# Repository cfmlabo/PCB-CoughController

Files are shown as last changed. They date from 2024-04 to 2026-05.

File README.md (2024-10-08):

# カフコントローラ用基板

- カフスイッチ(Switch + LED)最大５+２個  
  - J9は予備(SW6, SW7)なので実装しなくてよい
- オーディオリレー  
  - APSでは使用しないので実装しなくてよい
- GPIO(IN 8/OUT 8)  

[BOM](./BOM.md)

## CPI-DIO対応表

### Board1 / IN

| ピン番号 | 機能 |
| -- | -- |
| 1 | NC |
| 2 | SW 7 |
| 3 | SW 6 |
| 4 | SW 5 |
| 5 | SW 4 |
| 6 | SW 3 |
| 7 | SW 2 |
| 8 | SW 1 |

### Board1 / OUT

| ピン番号 | 機能 |
| -- | -- |
| 1 | リレー |
| 2 | SW 7 |
| 3 | SW 6 |
| 4 | SW 5 |
| 5 | SW 4 |
| 6 | SW 3 |
| 7 | SW 2 |
| 8 | SW 1 |

### Board2 / IN

| ピン番号 | 機能 |
| -- | -- |
| 1 | IN 8 |
| 2 | IN 7 |
| 3 | IN 6 |
| 4 | IN 5 |
| 5 | IN 4 |
| 6 | IN 3 |
| 7 | IN 2 |
| 8 | IN 1 |

### Board2 / OUT

| ピン番号 | 機能 |
| -- | -- |
| 1 | OUT 8 |
| 2 | OUT 7 |
| 3 | OUT 6 |
| 4 | OUT 5 |
| 5 | OUT 4 |
| 6 | OUT 3 |
| 7 | OUT 2 |
| 8 | OUT 1 |

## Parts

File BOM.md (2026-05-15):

# 部品一覧表

| No. | Ref | 数量 | 部品名 | 名称 | |
| -- | -- | -- | -- | -- | -- |
| 1 | C1 | 1 | 0.1uF | セラミックコンデンサ | [秋月](https://akizukidenshi.com/catalog/g/g100090/) |
| 2 | C2 | 1 | 100uF/25V | 電解コンデンサ | [秋月](https://akizukidenshi.com/catalog/g/g117877/) |
| 3 | D1, D2 | 2 | 1S1588 | 整流ダイオード | [秋月(代替品)](https://akizukidenshi.com/catalog/g/g116835/) |
| 4 | J1, J2, J3, J4, J5, J6 | 6 | 2x10 | ピンヘッダ(ボックス) | [秋月](https://akizukidenshi.com/catalog/g/g113180/)|
| 5 | K1, K2 | 2 | G6A-274P DC5V | リレー | [モノタロウ](https://www.monotaro.com/p/4080/2257/)|
| 6 | R1, R2, R6, R7 | 4 | 10K | 抵抗 | 社内在庫品 |
| 7 | R3, R4, R5, R8 | 4 | 220 | 抵抗 | 社内在庫品 |
| 8 | R9, R10, R11, R12, R13, R14, R15, R16, R17, R18, R19, R20, R21, R22, R23, R24 | 16 | 510 | 抵抗 | 社内在庫品 |
| 9 | U1, U2, U3, U4, U5, U6, U7, U8 | 8 | TLP224-2 | フォトリレー | 社内在庫品 |

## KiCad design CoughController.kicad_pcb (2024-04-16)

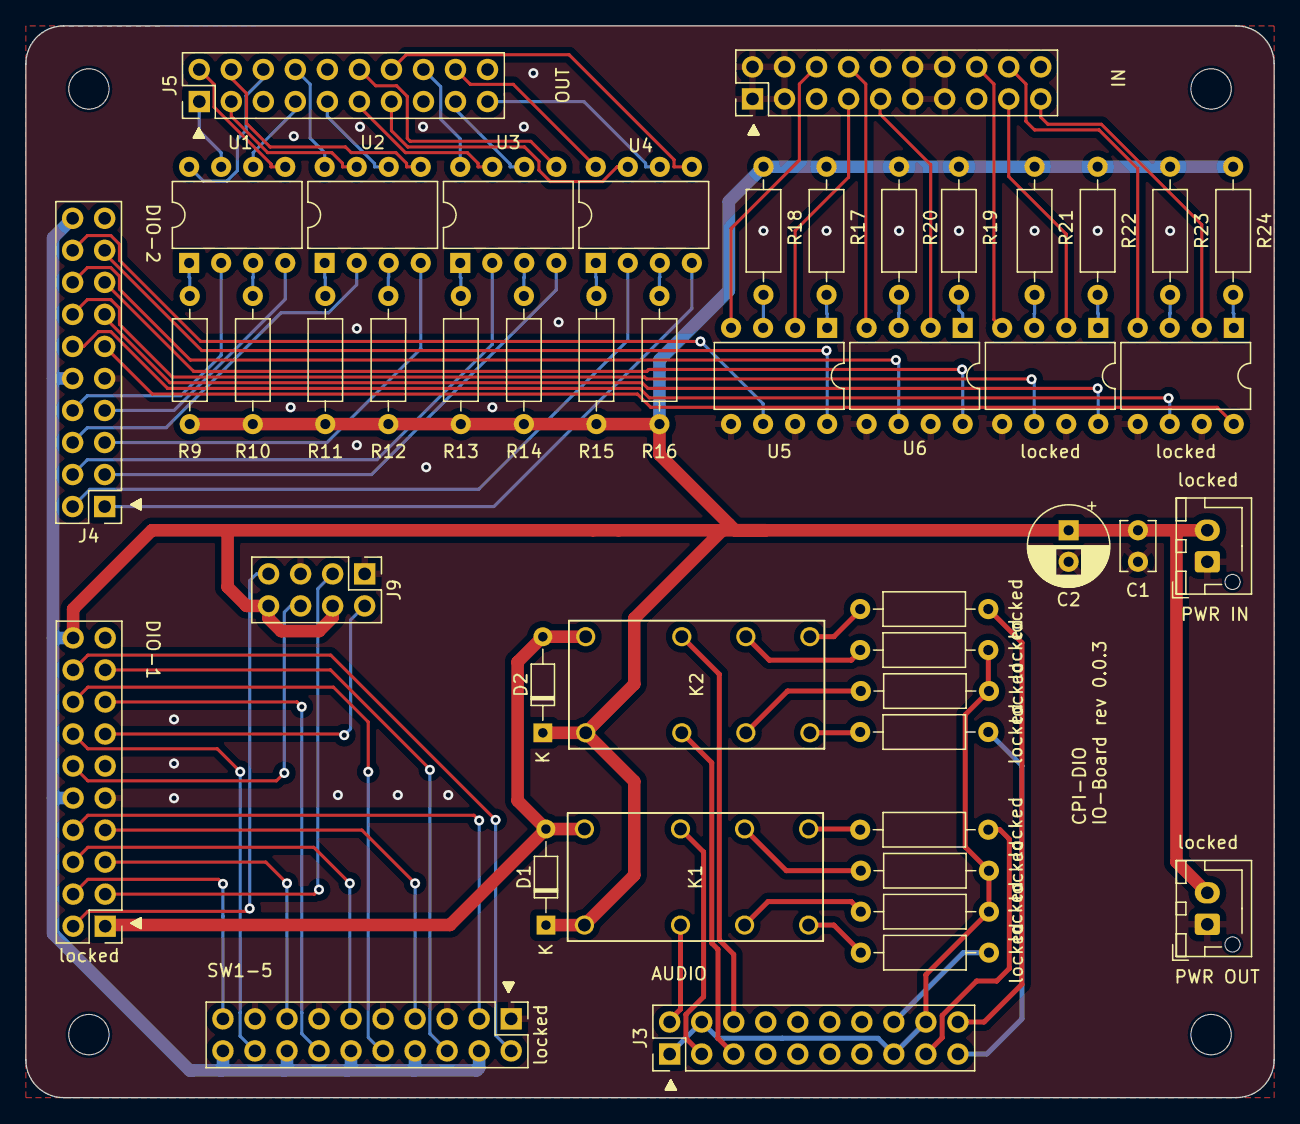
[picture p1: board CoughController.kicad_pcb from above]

Board: 2 copper layers, 99.0 x 85.0 mm, 51 parts (0 on the bottom side), 90 nets.

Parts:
C1: 0.1uF; C_Disc_D3.8mm_W2.6mm_P2.50mm
C2: 100uF/25V; CP_Radial_D6.3mm_P2.50mm
D1, D2: 1S1588; D_DO-34_SOD68_P7.62mm_Horizontal
H1, H2, H3, H4: MountingHole; MountingHole_3.2mm_M3
J3: AUDIO IN/OUT; BoxHeader_2x10_P2.54mm_Vertical
J4: DIO-2; BoxHeader_2x10_P2.54mm_Vertical
J5: GPIO-OUT; BoxHeader_2x10_P2.54mm_Vertical
J6: GPIO-IN; BoxHeader_2x10_P2.54mm_Vertical
J9: Conn_02x04_Odd_Even; PinHeader_2x04_P2.54mm_Vertical
K1, K2: G6A-274P-DC5; RELAY_G6A-274P-DC5
R9, R10, R11, R12, R13, R14, R15, R16, R17, R18, R19, R20, R21, R22, R23, R24: 510; R_Axial_DIN0207_L6.3mm_D2.5mm_P10.16mm_Horizontal
U1, U2, U3, U4, U5, U6: TLP627-2; DIP-8_W7.62mm
locked: SW1-5; BoxHeader_2x10_P2.54mm_Vertical
locked#2, locked#7: TLP627-2; DIP-8_W7.62mm
locked#3, locked#4, locked#9, locked#10: 10K; R_Axial_DIN0207_L6.3mm_D2.5mm_P10.16mm_Horizontal
locked#5, locked#12, locked#13, locked#14: 220; R_Axial_DIN0207_L6.3mm_D2.5mm_P10.16mm_Horizontal
locked#6: DIO-1; BoxHeader_2x10_P2.54mm_Vertical
locked#8: PWR_IN; JST_XH_B2B-XH-AM_1x02_P2.50mm_Vertical
locked#11: PWR_OUT; JST_XH_B2B-XH-AM_1x02_P2.50mm_Vertical

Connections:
AUDIO-IN-L-COLD: J3.3, K1.13
AUDIO-IN-L-GND: J3.1, J3.4, J3.15, J3.18, locked#3.2, locked#4.2, locked#9.1, locked#10.1
AUDIO-IN-L-HOT: J3.2, K1.4
AUDIO-IN-R-COLD: J3.6, K2.13
AUDIO-IN-R-HOT: J3.5, K2.4
AUDIO-OUT-L-COLD: J3.17, locked#14.1
AUDIO-OUT-L-HOT: J3.16, locked#13.2
AUDIO-OUT-R-COLD: J3.20, locked#5.2
AUDIO-OUT-R-HOT: J3.19, locked#12.1
COM0: C1.1, C2.1, D1.1 (K), D2.1 (K), J4.10, J4.20, J9.4, J9.8, K1.1, K2.1, R9.2, R10.2, R11.2, R12.2, R13.2, R14.2, R15.2, R16.2, R17.2, R18.2, R19.2, R20.2, R21.2, R22.2, R23.2, R24.2, locked.4, locked.8, locked.12, locked.16, locked.20, locked#6.10, locked#6.20, locked#8.2, locked#11.2
DIO-2/IN1: J4.18, U5.6
DIO-2/IN2: J4.17, U5.8
DIO-2/IN3: J4.16, U6.6
DIO-2/IN4: J4.15, U6.8
DIO-2/IN5: J4.14, locked#7.6
DIO-2/IN6: J4.13, locked#7.8
DIO-2/IN7: J4.12, locked#2.6
DIO-2/IN8: J4.11, locked#2.8
DIO-2/OUT1: J4.8, U1.2
DIO-2/OUT2: J4.7, U1.4
DIO-2/OUT3: J4.6, U2.2
DIO-2/OUT4: J4.5, U2.4
DIO-2/OUT5: J4.4, U3.2
DIO-2/OUT6: J4.3, U3.4
DIO-2/OUT7: J4.2, U4.2
DIO-2/OUT8: J4.1, U4.4
GND: C1.2, C2.2, J4.9, J6.1, J6.2, J6.3, J6.4, J6.11, J6.12, J6.13, J6.14, J9.1, J9.5, U5.5, U5.7, U6.5, U6.7, locked.1, locked.5, locked.9, locked.13, locked.17, locked#2.5, locked#2.7, locked#6.9, locked#7.5, locked#7.7, locked#8.1, locked#11.1
GPIO-IN/1P: J6.6, U5.4
GPIO-IN/2P: J6.7, U5.2
GPIO-IN/3P: J6.8, U6.4
GPIO-IN/4P: J6.9, U6.2
GPIO-IN/5P: J6.16, locked#7.4
GPIO-IN/6P: J6.17, locked#7.2
GPIO-IN/7P: J6.18, locked#2.4
GPIO-IN/8P: J6.19, locked#2.2
GPIO-OUT/1M: J5.1, U1.7
GPIO-OUT/1P: J5.6, U1.8
GPIO-OUT/2M: J5.2, U1.5
GPIO-OUT/2P: J5.7, U1.6
GPIO-OUT/3M: J5.3, U2.7
GPIO-OUT/3P: J5.8, U2.8
GPIO-OUT/4M: J5.4, U2.5
GPIO-OUT/4P: J5.9, U2.6
GPIO-OUT/5M: J5.11, U3.7
GPIO-OUT/5P: J5.16, U3.8
GPIO-OUT/6M: J5.12, U3.5
GPIO-OUT/6P: J5.17, U3.6
GPIO-OUT/7M: J5.13, U4.7
GPIO-OUT/7P: J5.18, U4.8
GPIO-OUT/8M: J5.14, U4.5
GPIO-OUT/8P: J5.19, U4.6
unnamed: K1.6, locked#9.2
unnamed: K1.8, locked#13.1
unnamed: K1.9, locked#14.2
unnamed: K1.11, locked#3.1
unnamed: K2.6, locked#10.2
unnamed: K2.8, locked#12.2
unnamed: K2.9, locked#5.1
unnamed: K2.11, locked#4.1
unnamed: R9.1, U1.1
unnamed: R10.1, U1.3
unnamed: R11.1, U2.1
unnamed: R12.1, U2.3
unnamed: R13.1, U3.1
unnamed: R14.1, U3.3
unnamed: R15.1, U4.1
unnamed: R16.1, U4.3
unnamed: R17.1, U5.1
unnamed: R18.1, U5.3
unnamed: R19.1, U6.1
unnamed: R20.1, U6.3
unnamed: R21.1, locked#7.3
unnamed: R22.1, locked#7.1
unnamed: R23.1, locked#2.3
unnamed: R24.1, locked#2.1
RY_POW: D1.2 (A), D2.2 (A), K1.16, K2.16, locked#6.1
SW1/L1: locked.3, locked#6.8
SW1/O: locked.2, locked#6.18
SW2/L1: locked.7, locked#6.7
SW2/O: locked.6, locked#6.17
SW3/L1: locked.11, locked#6.6
SW3/O: locked.10, locked#6.16
SW4/L1: locked.15, locked#6.5
SW4/O: locked.14, locked#6.15
SW5/L1: locked.19, locked#6.4
SW5/O: locked.18, locked#6.14
SW6/L1: J9.3, locked#6.3
SW6/O: J9.2, locked#6.13
SW7/L1: J9.7, locked#6.2
SW7/O: J9.6, locked#6.12

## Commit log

2024-03-14 カフコントローラ
    [CoughController.kicad_pcb, CoughController.kicad_sch, DIO1.kicad_sch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]
2024-03-14 コネクタをピンヘッダに変更
    [CoughController.kicad_pcb, DIO1.kicad_sch, DIO2.kicad_sch]
2024-03-14 基板サイズ調整
    [CoughController.kicad_pcb]
2024-03-14 ルーティング見直し
    [CoughController.kicad_pcb]
2024-03-15 端子をピンヘッダ2x10に変更
    [CoughController.kicad_pcb, CoughController.kicad_sch, DIO1.kicad_sch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]
2024-03-29 電源コネクタ フットプリント間違いを修正
    [CoughController.kicad_pcb, CoughController.kicad_sch]
2024-03-29 リレーのフットプリントが間違っていたのを修正
    ピン配置が間違っていた
    [CoughController.kicad_pcb]
2024-03-29 GPIO OUT ジックミスを修正
    電流シンクに変更
    [CoughController.kicad_pcb, DIO2.kicad_sch]
2024-03-29 オーディオ線強化
    [CoughController.kicad_pcb]
2024-04-03 リレー ロジックミス修正
    [CoughController.kicad_pcb, DIO1.kicad_sch]
2024-04-04 AUDIO ソケット位置調整
    ソケットピンヘッダが干渉するので移動
    [CoughController.kicad_pcb]
2024-04-08 SW6/SW7を追加
    [CoughController.kicad_pcb, CoughController.kicad_sch, DIO1.kicad_sch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]
2024-04-08 リファクタリング
    [CoughController.kicad_pcb]
2024-04-08 bugfix GPIO/IN ドライ接点へ修正
    GPIO/INはドライ接点
    [CoughController.kicad_pcb, CoughController.kicad_sch, DIO2.kicad_sch]
2024-04-16 rename Symbol and Footprint of relay.
    [CoughController.kicad_pcb, DIO1.kicad_sch]
2024-04-16 fix footprint of relay
    [CoughController.kicad_pcb]
2024-04-30 add table of pin function
2024-10-08 README更新
